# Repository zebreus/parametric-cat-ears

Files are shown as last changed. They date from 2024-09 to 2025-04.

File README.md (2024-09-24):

# parametric-cat-ears

A parametric version of the 3d printed cat ears often seen at CCC events.

You can customize the parameters and generate an STL with the [online customizer](https://custom.wirs.ing/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).

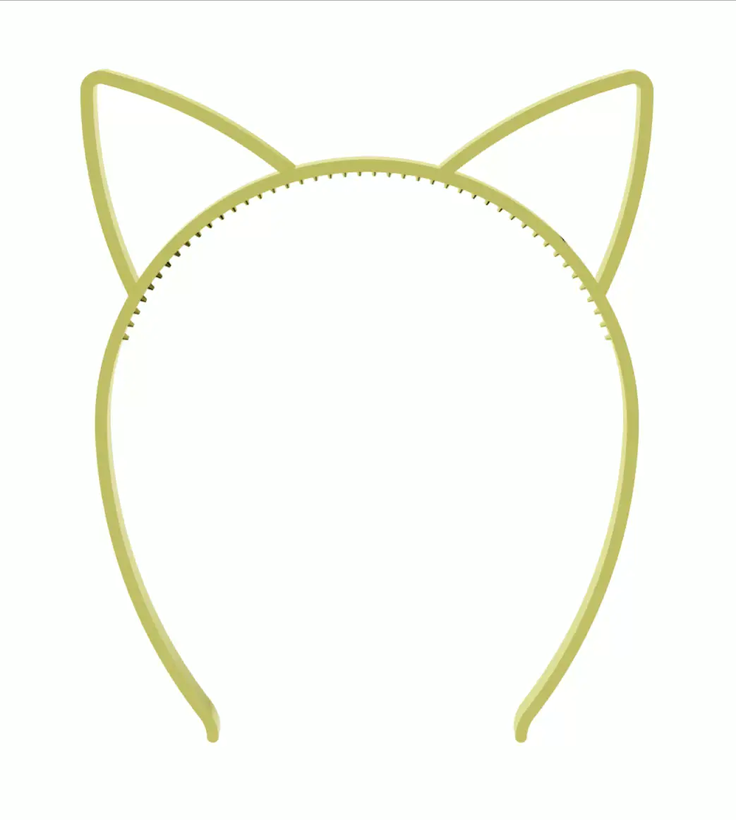
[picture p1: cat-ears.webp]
[](https://custom.wirs.ing/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)

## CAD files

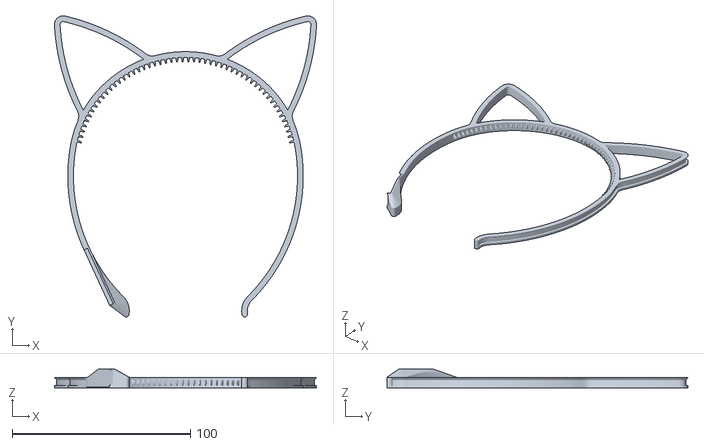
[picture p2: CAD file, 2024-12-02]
cat-ears.stl
147.0 x 168.8 x 10.6

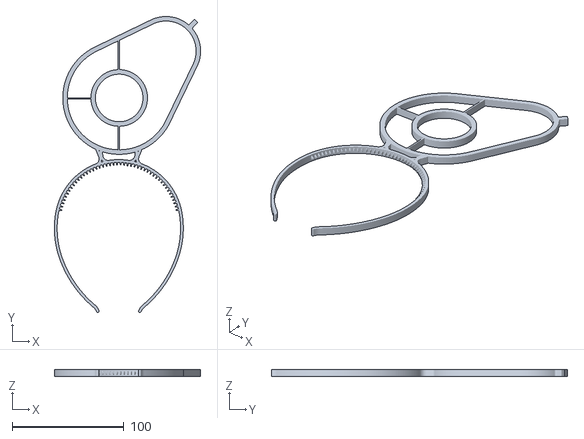
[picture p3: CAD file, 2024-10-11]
avocadoom-ears.stl
130.7 x 264.5 x 6.00

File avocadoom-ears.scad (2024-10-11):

/*[ Headband ]*/

// Radius of the circle that makes up the upper half of the headband
upperRadius = 56; // [20:120]
// This angle determines the size of the upper half
upperAngle = 80; // [40:140]
// Radius of the circle that makes up the middle part of the headband
middleRadius = 80; // [20:120]
// This angle determines the size of the middle part of the headband
middleAngle = 30; // [0:90]
// This angle determines the size of the bottom half
bottomAngle = 30; // [0:120]
// Radius of the partial circles of the bottom half
bottomRadius = 100; // [20:600]
// Radius of the end bits at the very bottom
endRadius = 10; // [0:50]

// Height of the headband
height = 6; // [0:0.1:30]
// Width of the headband
width = 2.5; // [0:0.1:30]

/*[ Ears ]*/

// Where the ears are located on the headband
earPositionAngle = 15; // [0:90]

// Radius of the curvature of the ears sides
earRadius = 120; // [10:500]
// Roughly how the ears are
earLength = 13; // [10:500]
// The width of the ears
earWidth = 12; // [10:120]
// How wide the tip of the ear is
earTipWidth = 3; // [2:40]
// How big the angle of the ears base is
earConnectorRadius = 6; // [2:50]

/*[ Spikes ]*/

// How much of the upper ring has spikes (in degrees)
// Should be smaller than upperAngle otherwise spikes will be detached
spikesAngle = 80; // [0:120]
// How long the spikes are. Increase for more grip
spikeDepth = 2.5; // [0:0.1:10]
// How high the spikes are.
spikeHeight = 4; // [0:0.1:10]
// How high the spikes are at the tip.
spikeHeightEnd = 1.5; // [0:0.1:10]
// How wide the spikes are.
spikeWidth = 1.4; // [0:0.1:20]
// Spikes per cm
spikeDensity = 3; // [0.1:0.01:20]

/*[ Rudelblinken ]*/

// Enable support for a rudelblinken PCB
enableRudelblinken = false;

/*[ LED recess ]*/

// How deep the recess should be
recessDepth = 0.0; // [0.0:0.01:5.0]
// How wide the recess should be
recessWidth = 4; // [0:0.1:20]

// Secret section with a boring name
/*[ About ]*/

// How good you are at hearing
hearingAbility = 2; // [0:1:10]

// Enable extra protection
protection = false;

/*[ Hidden ]*/
rudelblinken_board_height = 1.7;
rudelblinken_board_length = 34.2;

module mirror_copy(vector)
{
    children();
    mirror(vector) children();
}

// recessSide can be "outer" or "inner"
module angled_thing(r, angle, h = height, spikesAngle = 0, spikeOffset = 0, recessSide = "outer")
{
    translate([ -r, 0, 0 ])
    rotate_extrude(convexity = 10, $fa = 0.01, angle = angle)
    translate([ r, 0, 0 ])
    mirror([recessSide == "inner" ? 1 : 0,0,0])
    polygon([
        [width/2, h/2],
        // [width/2, h/2 - recessWidth/2],
        [width/2, min(h/2,recessWidth/2 + abs(recessDepth))],
        [width/2 - recessDepth, recessWidth/2],
        [width/2 - recessDepth, -recessWidth/2],
        [width/2, -recessWidth/2],
        [width/2, -h/2],
        [-width/2, -h/2],
        [-width/2, h/2]]);
    // square([ width, h ], center = true);

    // Spikes if requested
    spikesDirection = spikesAngle > 0 ? 1 : -1;
    spikesAngle = abs(spikesAngle);
    distance = r * 2 * PI * (spikesAngle / 360);
    spikeDistance = 10 / spikeDensity;
    spikeAngleDistance = spikesAngle / (distance / spikeDistance);
    spikeOffset = ((((0.5 * spikeDistance) -abs(spikeOffset) )% spikeDistance)+spikeDistance)%spikeDistance;
    spikeAngleOffset =  spikesAngle / (distance / spikeOffset);
    for (spikeAngle = [spikeAngleOffset:spikeAngleDistance:spikesAngle])
    {
        translate([ -r, 0, 0 ])
        rotate([ 0, 0, spikesDirection * spikeAngle])
        translate([ r - width / 2, 0, 0 ])
        rotate([0,0,-90])
        spike();
    }
    if (protection){
        spikesDirection = angle > 0 ? 1 : -1;
        spikesAngle = abs(angle);
        distance = r * 2 * PI * (spikesAngle / 360);
        spikeDistance = 10 / spikeDensity;
        spikeAngleDistance = spikesAngle / (distance / spikeDistance);
        spikeOffset = ((((0.5 * spikeDistance) -abs(spikeOffset) )% spikeDistance)+spikeDistance)%spikeDistance;
        spikeAngleOffset =  spikesAngle / (distance / spikeOffset);
        for (spikeAngle = [spikeAngleOffset:spikeAngleDistance:abs(angle)])
        {
            translate([ -r, 0, 0 ])
            rotate([ 0, 0, spikesDirection * spikeAngle])
            translate([ r - width / 2, 0, 0 ])
            translate([recessSide == "inner" ? 0 : width,0,0]) 
            rotate([0,0,recessSide == "inner" ? -90 : 90])
            spike();
        }
    }
}

module shift_angled(r = 0, angle = 0)
{
    translate([ -r, 0, 0 ])
    rotate([ 0, 0, angle ])
    translate([ r, 0, 0 ])
    children();
}

function dist(p1, p2) = sqrt(pow(p2[0] - p1[0], 2) + pow(p2[1] - p1[1], 2));


// module funny_beam(start_angle=45,length=50, r1=10, r2=20){

//     center_a = [r1*cos(start_angle),r1*sin(start_angle)];
//     center_b = [0 , length];

//     rr1 = r1+r2;
//     rr2 = r2;

//     d = dist(center_a, center_b);

//     // Find the point P2 which is the point where the line through the intersection points crosses the line between the circle centers
//     l = (rr1^2 - rr2^2 + d^2) / (2 * d);

//     // Distance from P2 to the intersection points
//     h = sqrt(rr1 ^ 2 - l ^ 2);

//     center_c = [
//         (l/d)*(center_b[0]-center_a[0]) - (h/d)*(center_b[1]-center_a[1]) + center_a[0],
//         (l/d)*(center_b[1]-center_a[1]) + (h/d)*(center_b[0]-center_a[0]) + center_a[1],
//     ];

//     angle_ca = atan2(center_c[1]-center_a[1], center_c[0]-center_a[0]);
//     angle_cb = atan2(center_c[1]-center_b[1], center_c[0]-center_b[0]);
//     angle_connection = start_angle + 180 - angle_ca;

//     mirror([1,0,0])
//     rotate([0,0,-start_angle]){
//     %angled_thing(r = r1, angle = angle_connection);
//     shift_angled(r = r1, angle = angle_connection)
//     mirror([1,0,0])
//     %angled_thing(r = r2, angle =  (360+angle_cb -angle_ca) %360);
//     }


// }
// funny_beam();

// A single ear. Centered
module ear(start_angle=0){
    r1=earConnectorRadius;
    r2=earRadius;

    earSideWidth = (earWidth - earTipWidth)/2;
    earSideHeight = earLength;
    earSideLength = sqrt(earSideWidth^2 + earSideHeight^2);

    earSideAngle = atan(earSideWidth/earSideHeight);

    start_angle = 90 - earSideAngle - start_angle;


    center_a = [r1*cos(start_angle),r1*sin(start_angle)];
    center_b = [0 , earSideLength];

    rr1 = r1+r2;
    rr2 = r2;

    d = dist(center_a, center_b);

    // Find the point P2 which is the point where the line through the intersection points crosses the line between the circle centers
    l = (rr1^2 - rr2^2 + d^2) / (2 * d);

    // Distance from P2 to the intersection points
    h = sqrt(rr1 ^ 2 - l ^ 2);

    center_c = [
        (l/d)*(center_b[0]-center_a[0]) - (h/d)*(center_b[1]-center_a[1]) + center_a[0],
        (l/d)*(center_b[1]-center_a[1]) + (h/d)*(center_b[0]-center_a[0]) + center_a[1],
    ];

    angle_ca = atan2(center_c[1]-center_a[1], center_c[0]-center_a[0]);
    angle_cb = atan2(center_c[1]-center_b[1], center_c[0]-center_b[0]);
    angle_connection = start_angle + 180 - angle_ca;
    angle_side = (360+angle_cb -angle_ca) %360;
    angle_tip = 90-(angle_side + start_angle - angle_connection)-earSideAngle;

    tip_radius = earTipWidth /2 / sin(angle_tip) ;

    mirror_copy([1,0,0])
    translate([earWidth/2,0,0]) 
    rotate([0,0,earSideAngle])
    mirror([1,0,0])
    rotate([0,0,-start_angle]){
    angled_thing(r = r1, angle = angle_connection, recessSide = "inner");
    shift_angled(r = r1, angle = angle_connection)
    mirror([1,0,0]){
    angled_thing(r = r2, angle =  angle_side);
    shift_angled(r = r2, angle = angle_side )
    angled_thing(r = tip_radius, angle = angle_tip, spikeOffset = r1 * sin(angle_side)  );
    }
    }
}

module lower_half(enableRudelblinken = enableRudelblinken) {
     // Main beam until the rudelblinke board
    angled_thing(r = bottomRadius, angle = -bottomAngle + rudelblinken_board_angle_length);

    bottom_circumference = bottomRadius * 2 * PI;
    rudelblinken_board_angle_length = 360 * (rudelblinken_board_length / bottom_circumference);
    shift_angled(r = bottomRadius, angle = -bottomAngle + rudelblinken_board_angle_length)
    if (enableRudelblinken){
    second_lower_half_with_rudelblinken();
    }else {

    second_lower_half_without_rudelblinken(angle = rudelblinken_board_angle_length);
    }
}
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

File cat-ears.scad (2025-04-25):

/*[ Headband ]*/

// Radius of the circle that makes up the upper half of the headband
upperRadius = 65; // [20:120]
// This angle determines the size of the upper half
upperAngle = 50; // [10:140]
// Radius of the circle that makes up the middle part of the headband
middleRadius = 60; // [20:120]
// This angle determines the size of the middle part of the headband
middleAngle = 30; // [0:90]
// This angle determines the size of the bottom half
bottomAngle = 55; // [0:120]
// Radius of the partial circles of the bottom half
bottomRadius = 97; // [20:600]
// Radius of the end bits at the very bottom
endRadius = 10; // [0:50]

// Height of the headband
height = 6; // [0:0.1:30]
// Width of the headband
width = 3.2; // [0:0.1:30]

/*[ Ears ]*/

// Where the ears are located on the headband
earPositionAngle = 40; // [0:90]

// Radius of the curvature of the ears sides
earRadius = 120; // [10:500]
// Roughly how the ears are
earLength = 50; // [10:500]
// The width of the ears
earWidth = 55; // [10:120]
// How wide the tip of the ear is
earTipWidth = 5; // [2:40]
// How big the angle of the ears base is
earConnectorRadius = 7; // [2:50]

/*[ Spikes ]*/

// How much of the upper ring has spikes (in degrees)
// Should be smaller than upperAngle otherwise spikes will be detached
spikesAngle = 80; // [0:120]
// How long the spikes are. Increase for more grip
spikeDepth = 2.5; // [0:0.1:10]
// How high the spikes are.
spikeHeight = 4; // [0:0.1:10]
// How high the spikes are at the tip.
spikeHeightEnd = 1.5; // [0:0.1:10]
// How wide the spikes are.
spikeWidth = 1.4; // [0:0.1:20]
// Spikes per cm
spikeDensity = 3; // [0.1:0.01:20]

/*[ Rudelblinken ]*/

// Enable support for a rudelblinken PCB
enableRudelblinken = false;

/*[ LED recess ]*/

// Where the recess for LED strips will be generated
recess = "none"; //["none", "full", "outside", "inside", "insideWithoutHeadband"]
headbandRecess = recess == "outside" || recess == "full" || recess == "inside";
outsideEarRecess = recess == "outside" || recess == "full";
insideEarRecess = recess == "inside" || recess == "full" || recess == "insideWithoutHeadband";


// How deep the recess should be
recessDepth = 1.2; // [0.0:0.01:5.0]
// How wide the recess should be
recessWidth = 3; // [0:0.1:20]

// Puch a hole into the base of the ears for for cables to the inside
cableHole = 0.0; // [0:0.1:10]
// If the cable hole should be open
cableHoleOpen = false;
// Make the cable hole extra big
cableHoleAspect = 1;

// Dont open this section
/*[ Other hacky options ]*/

// How good you are at hearing
hearingAbility = 2; // [0:1:10]

// Enable extra protection
protection = false;

// Secret section with a boring name
/*[ About ]*/

// If the headband should be horny
horny = false;

// This is required because I am too lazy to calculate the length
hornyRadius = 75; // [0:0.5:200]

// Another setting
hornyDiff = 0; // [-100:0.5:100]



/*[ Hidden ]*/
rudelblinken_board_height = 1;
rudelblinken_board_length = 34.2;

module mirror_copy(vector)
{
    children();
    mirror(vector) children();
}

// recessSide can be "outer" or "inner"
module angled_thing(r, angle, h = height, spikesAngle = 0, spikeOffset = 0, outsideRecess = false, insideRecess = false)
{
    outsideRecessDepth = outsideRecess ? recessDepth : 0;
    insideRecessDepth = insideRecess ? recessDepth : 0;

    outsideRecessWidth = outsideRecess ? recessWidth : 0;
    insideRecessWidth = insideRecess ? recessWidth : 0;

    translate([ -r, 0, 0 ])
    rotate_extrude(convexity = 10, $fa = 0.01, angle = angle)
    translate([ r, 0, 0 ])
    polygon([
        [width/2, h/2],
        // [width/2, h/2 - recessWidth/2],
        [width/2, min(h/2,outsideRecessWidth/2 + abs(outsideRecessDepth))],
        [width/2 - outsideRecessDepth, outsideRecessWidth/2],
        [width/2 - outsideRecessDepth, -outsideRecessWidth/2],
        [width/2, -outsideRecessWidth/2],
        [width/2, -h/2],
        [-width/2, -h/2],
        [-width/2, -insideRecessWidth/2],
        [-width/2 + insideRecessDepth, -insideRecessWidth/2],
        [-width/2 + insideRecessDepth, insideRecessWidth/2],
        [-width/2, min(h/2,insideRecessWidth/2 + abs(insideRecessDepth))],
        [-width/2, h/2]]);
    // square([ width, h ], center = true);

    // Spikes if requested
    spikesDirection = spikesAngle > 0 ? 1 : -1;
    spikesAngle = abs(spikesAngle);
    distance = r * 2 * PI * (spikesAngle / 360);
    spikeDistance = 10 / spikeDensity;
    spikeAngleDistance = spikesAngle / (distance / spikeDistance);
    spikeOffset = ((((0.5 * spikeDistance) -abs(spikeOffset) )% spikeDistance)+spikeDistance)%spikeDistance;
    spikeAngleOffset =  spikesAngle / (distance / spikeOffset);
    for (spikeAngle = [spikeAngleOffset:spikeAngleDistance:spikesAngle])
    {
        translate([ -r, 0, 0 ])
        rotate([ 0, 0, spikesDirection * spikeAngle])
        translate([ r - width / 2, 0, 0 ])
        rotate([0,0,-90])
        spike();
    }
    if (protection){
        spikesDirection = angle > 0 ? 1 : -1;
        spikesAngle = abs(angle);
        distance = r * 2 * PI * (spikesAngle / 360);
        spikeDistance = 10 / spikeDensity;
        spikeAngleDistance = spikesAngle / (distance / spikeDistance);
        spikeOffset = ((((0.5 * spikeDistance) -abs(spikeOffset) )% spikeDistance)+spikeDistance)%spikeDistance;
        spikeAngleOffset =  spikesAngle / (distance / spikeOffset);
        for (spikeAngle = [spikeAngleOffset:spikeAngleDistance:abs(angle)])
        {
            translate([ -r, 0, 0 ])
            rotate([ 0, 0, spikesDirection * spikeAngle])
            translate([ r - width / 2, 0, 0 ])
            translate([recessSide == "inner" ? 0 : width,0,0]) 
            rotate([0,0,recessSide == "inner" ? -90 : 90])
            spike();
        }
    }
}

module shift_angled(r = 0, angle = 0)
{
    translate([ -r, 0, 0 ])
    rotate([ 0, 0, angle ])
    translate([ r, 0, 0 ])
    children();
}

function dist(p1, p2) = sqrt(pow(p2[0] - p1[0], 2) + pow(p2[1] - p1[1], 2));


// module funny_beam(start_angle=45,length=50, r1=10, r2=20){

//     center_a = [r1*cos(start_angle),r1*sin(start_angle)];
//     center_b = [0 , length];

//     rr1 = r1+r2;
//     rr2 = r2;

//     d = dist(center_a, center_b);

//     // Find the point P2 which is the point where the line through the intersection points crosses the line between the circle centers
//     l = (rr1^2 - rr2^2 + d^2) / (2 * d);

//     // Distance from P2 to the intersection points
//     h = sqrt(rr1 ^ 2 - l ^ 2);

//     center_c = [
//         (l/d)*(center_b[0]-center_a[0]) - (h/d)*(center_b[1]-center_a[1]) + center_a[0],
//         (l/d)*(center_b[1]-center_a[1]) + (h/d)*(center_b[0]-center_a[0]) + center_a[1],
//     ];

//     angle_ca = atan2(center_c[1]-center_a[1], center_c[0]-center_a[0]);
//     angle_cb = atan2(center_c[1]-center_b[1], center_c[0]-center_b[0]);
//     angle_connection = start_angle + 180 - angle_ca;

//     mirror([1,0,0])
//     rotate([0,0,-start_angle]){
//     %angled_thing(r = r1, angle = angle_connection);
//     shift_angled(r = r1, angle = angle_connection)
//     mirror([1,0,0])
//     %angled_thing(r = r2, angle =  (360+angle_cb -angle_ca) %360);
//     }


// }
// funny_beam();

// A single ear. Centered
module ear(start_angle=0){
    r1=earConnectorRadius;
    r2=earRadius;

    earSideWidth = (earWidth - earTipWidth)/2;
    earSideHeight = earLength;
    earSideLength = sqrt(earSideWidth^2 + earSideHeight^2);

    earSideAngle = atan(earSideWidth/earSideHeight);

    start_angle = 90 - earSideAngle - start_angle;


    center_a = [r1*cos(start_angle),r1*sin(start_angle)];
    center_b = [0 , earSideLength];

    rr1 = r1+r2;
    rr2 = r2;

    d = dist(center_a, center_b);

    // Find the point P2 which is the point where the line through the intersection points crosses the line between the circle centers
    l = (rr1^2 - rr2^2 + d^2) / (2 * d);

    // Distance from P2 to the intersection points
    h = sqrt(rr1 ^ 2 - l ^ 2);

    center_c = [
        (l/d)*(center_b[0]-center_a[0]) - (h/d)*(center_b[1]-center_a[1]) + center_a[0],
        (l/d)*(center_b[1]-center_a[1]) + (h/d)*(center_b[0]-center_a[0]) + center_a[1],
    ];

    angle_ca = atan2(center_c[1]-center_a[1], center_c[0]-center_a[0]);
    angle_cb = atan2(center_c[1]-center_b[1], center_c[0]-center_b[0]);
    angle_connection = start_angle + 180 - angle_ca;
    angle_side = (360+angle_cb -angle_ca) %360;
    angle_tip = 90-(angle_side + start_angle - angle_connection)-earSideAngle;

    tip_radius = earTipWidth /2 / sin(angle_tip) ;
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

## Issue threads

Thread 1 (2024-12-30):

Whats the best material to print these?

Minionflo, 2024-12-30:
Hello,
what material would you recommend for the cat ears?

zebreus, 2024-12-30:
The current default settings were chosen with PETG in mind, so I recommend that. The size should be wide enough to comfortably fit on most heads and small enough to be stable.

If they were made of PLA they will widen when your wear them because the LED strip can get warm and PLA will keep the shape after it got bent. If you only have PLA available, I recommend adjusting the settings to make the headband a bit smaller to compensate for the bending.

Closed 2025-01-02.

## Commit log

2024-09-23 Add cat ears
    [cat-ears.scad, cat-ears.stl]
2024-09-23 Improve the scad for thingiverse customizer
    [cat-ears.scad, cat-ears.stl]
2024-09-24 Fix openscad section names
    [cat-ears.scad]
2024-09-24 Transform all variable to camel case
    [cat-ears.scad]
2024-09-24 Adjust the ranges for customizer values
    [cat-ears.scad]
2024-09-24 Adjust the default parameters
    [cat-ears.scad, cat-ears.stl]
2024-09-25 Add a space for a rudelblinken PCB
    [cat-ears.scad]
2024-09-25 Enable adjusting the upper angle
    [cat-ears.scad]
2024-09-25 Add an adjustable middle part
    [cat-ears.scad]
2024-09-25 Rework ears
    [cat-ears.scad]
2024-09-25 Add recess for LED strips
    [cat-ears.scad]
2024-09-25 Fix recess calculation
    [cat-ears.scad]
2024-09-25 Fix parameter ranges
    [cat-ears.scad]
2024-09-25 Add option to adjust the hearing ability
    [cat-ears.scad]
2024-09-25 Increase security
    [cat-ears.scad]
2024-09-26 Adjust default parameters
    [cat-ears.scad]
2024-09-30 Try to fix recessDepth parameter
    [cat-ears.scad]
2024-09-30 Adjust board size
    [cat-ears.scad]
2024-10-11 Add avocadooms headgear
    [avocadoom-ears.scad, avocadoom-ears.stl]
2024-10-11 Fix some weird shifts
    [cat-ears.scad]
2024-10-22 Add horns
    [cat-ears.scad]
2024-10-26 Allow omitting recess in angle_thing
    [cat-ears.scad]
2024-10-26 Only provide LED strip recess on inside of ears
    Also leave a gap between the headband and the ear to thread wires/LED
    strip through. This is still a bit narrower than it should be (risk of
    breaking soldered connections on LED strip), but already works.
    This makes the attachment of the ears to the headband significantly
    weaker, and should be compensated for by filling the gap (or the
    entire ear for diffusion purposes) with glue once the electronics are
    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
    [cat-ears.scad]
2024-10-26 Make the wire gap a little bigger
    [cat-ears.scad]
2024-10-26 Default to recess for 2.7mm LED strip
    https://www.aliexpress.com/item/1005006618544267.html fits in here
    nicely.
    [cat-ears.scad]
2024-10-26 Add configuration option for LED strip recess locations
    [cat-ears.scad]
2024-10-26 Add options for a hole to the inside of the ear
    [cat-ears.scad]
2024-11-13 Remove recesses by default
    [cat-ears.scad]
2024-11-13 Update rudelblinken option for new boards
    [cat-ears.scad]
2024-11-13 Update generated stl
    [cat-ears.stl]
2024-11-18 Adjust headband width
    [cat-ears.scad]
2024-11-18 Attempt to make headband wider
    [cat-ears.scad]
2024-12-02 Adjust defaults
    [cat-ears.scad]
2024-12-02 Update STL
    [cat-ears.stl]
2025-04-25 Adjust PCB shape
    [cat-ears.scad]
